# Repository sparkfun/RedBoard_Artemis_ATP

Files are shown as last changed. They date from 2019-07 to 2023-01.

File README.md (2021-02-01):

SparkFun RedBoard Artemis ATP
============================

SparkFun RedBoard Artemis ATP

[*SparkFun RedBoard Artemis ATP (DEV-15442)*](https://www.sparkfun.com/products/15442)

The RedBoard Artemis ATP is affectionately called 'All the Pins!' at SparkFun. The Artemis module has 48 GPIO and this board breaks out absolutely every one of them in a familiar Mega like form factor. What's with the silkscreen labels? They're all over the place. We decided to label the pins as they are assigned on the Apollo3 IC itself. This makes finding the pin with the function you desire a lot easier. Have a look at the [full pin map](https://cdn.sparkfun.com/assets/8/2/3/3/c/Apollo3_Pad_Mapping.pdf) from the Apollo3 datasheet. If you really need to test out the 4-bit SPI functionality of the Artemis you're going to need to access pins 4, 22, 23, and 26. Need to try out the differential ADC port 1? Pins 14 and 15. The RedBoard Artemis ATP will allow you to flex the impressive capabilities of the Artemis module.

The RedBoard Artemis ATP has the improved power conditioning and USB to serial that we've refined over the years on our RedBoard line of products. A modern USB-C connector make programming easy. A Qwiic connector makes I<sup>2</sup>C easy. The ATP is fully compatible with SparkFun's Arduino core and can be programmed easily under the Arduino IDE. We've exposed the JTAG connector for more advanced users who prefer to use the power and speed of professional tools. If you need a *lot* of a GPIO with a simple to program, ready to go to market module, the ATP is the fix you need. We've added a digital MEMS microphone for folks wanting to experiment with always-on voice commands with TensorFlow and machine learning. We've even added a convenient jumper to measure current consumption for low power testing.

With 1M flash and 384k RAM you'll have plenty of room for your sketches. The Artemis module runs at 48MHz with a 96MHz turbo mode available and with Bluetooth to boot!

The SparkFun RedBoard Artemis ATP is a powerful platform if you're interesting in testing out the full capabilities of the SparkFun Artemis module. If you're looking for more compact solution, be sure to checkout our Nano and Uno footprints for more hacker friendly products.

Repository Contents
-------------------
* **/Hardware** - Eagle design files (.brd, .sch)

Documentation
-------------------
* **[Hookup Guide for the RedBoard Artemis ATP](https://learn.sparkfun.com/tutorials/hookup-guide-for-the-sparkfun-redboard-artemis-atp)**
* **[Artemis Development with Arduino](https://learn.sparkfun.com/tutorials/artemis-development-with-arduino)**
* **[Ambiq Apollo3 SDK SetUp](https://learn.sparkfun.com/tutorials/using-sparkfun-edge-board-with-ambiq-apollo3-sdk)**
* **[Designing with the SparkFun Artemis](https://learn.sparkfun.com/tutorials/designing-with-the-sparkfun-artemis)**
* **[CH340E USB to serial IC Drivers](https://www.sparkfun.com/ch340)**

License Information
-------------------

This product is _**open source**_! 

Please review the LICENSE.md file for license information. 

If you have any questions or concerns on licensing, please contact techsupport@sparkfun.com.

Please use, reuse, and modify these files as you see fit. Please maintain attribution to SparkFun Electronics and release any derivative under the same license.

Distributed as-is; no warranty is given.

- Your friends at SparkFun.

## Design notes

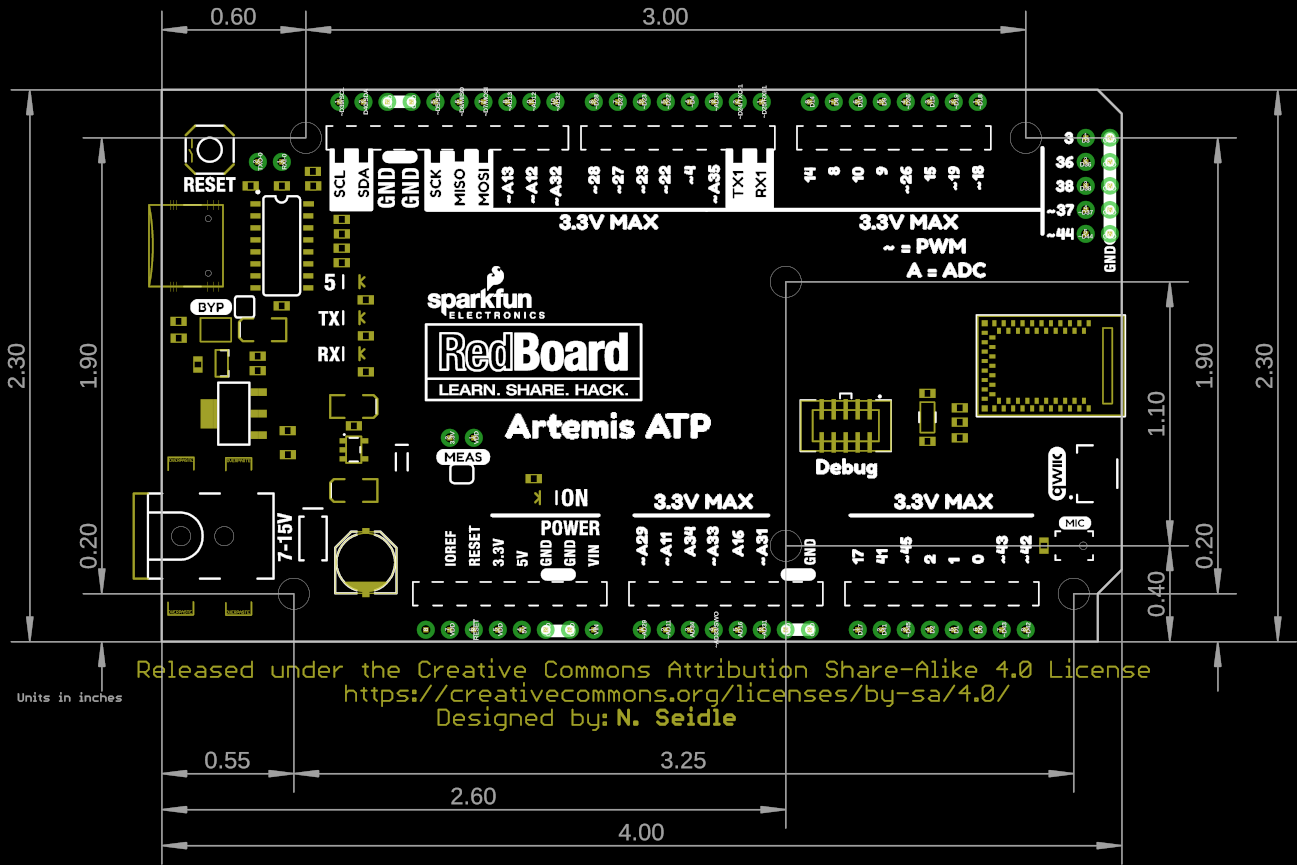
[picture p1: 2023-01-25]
Hardware/Artemis_ATP_Dimensions.png

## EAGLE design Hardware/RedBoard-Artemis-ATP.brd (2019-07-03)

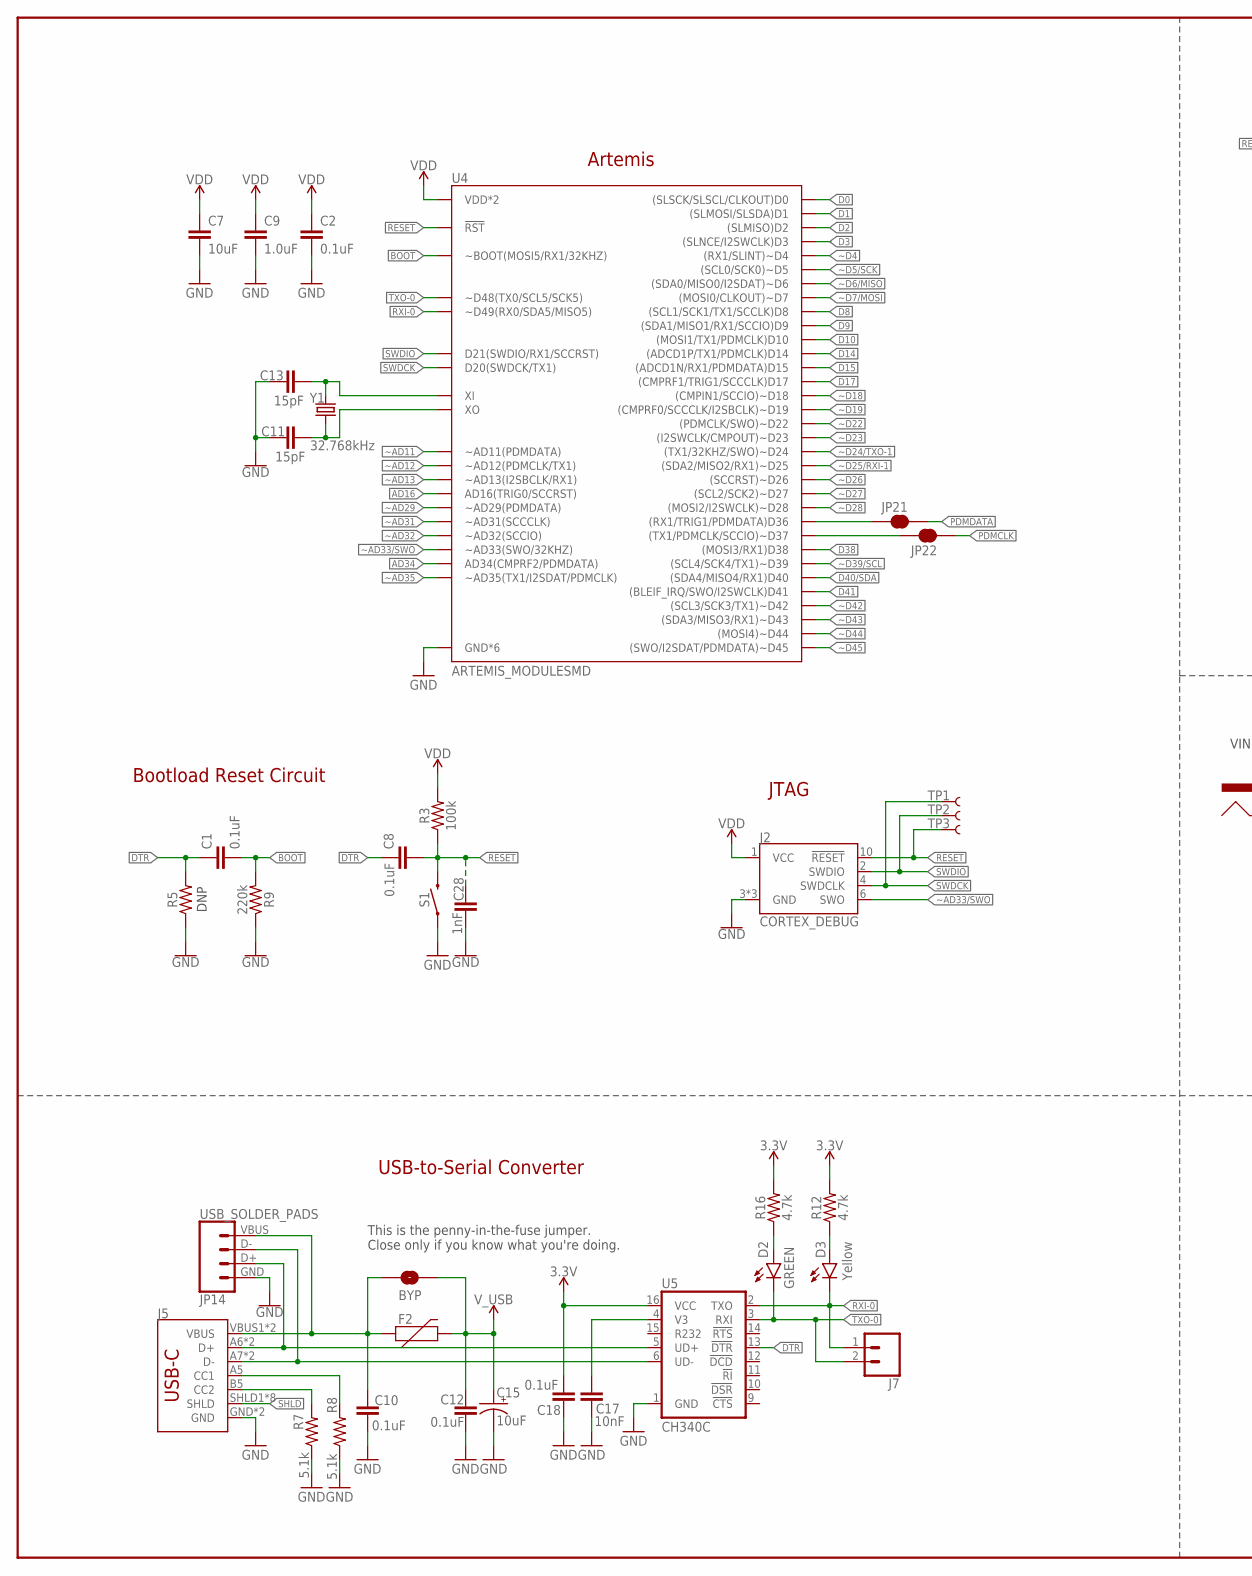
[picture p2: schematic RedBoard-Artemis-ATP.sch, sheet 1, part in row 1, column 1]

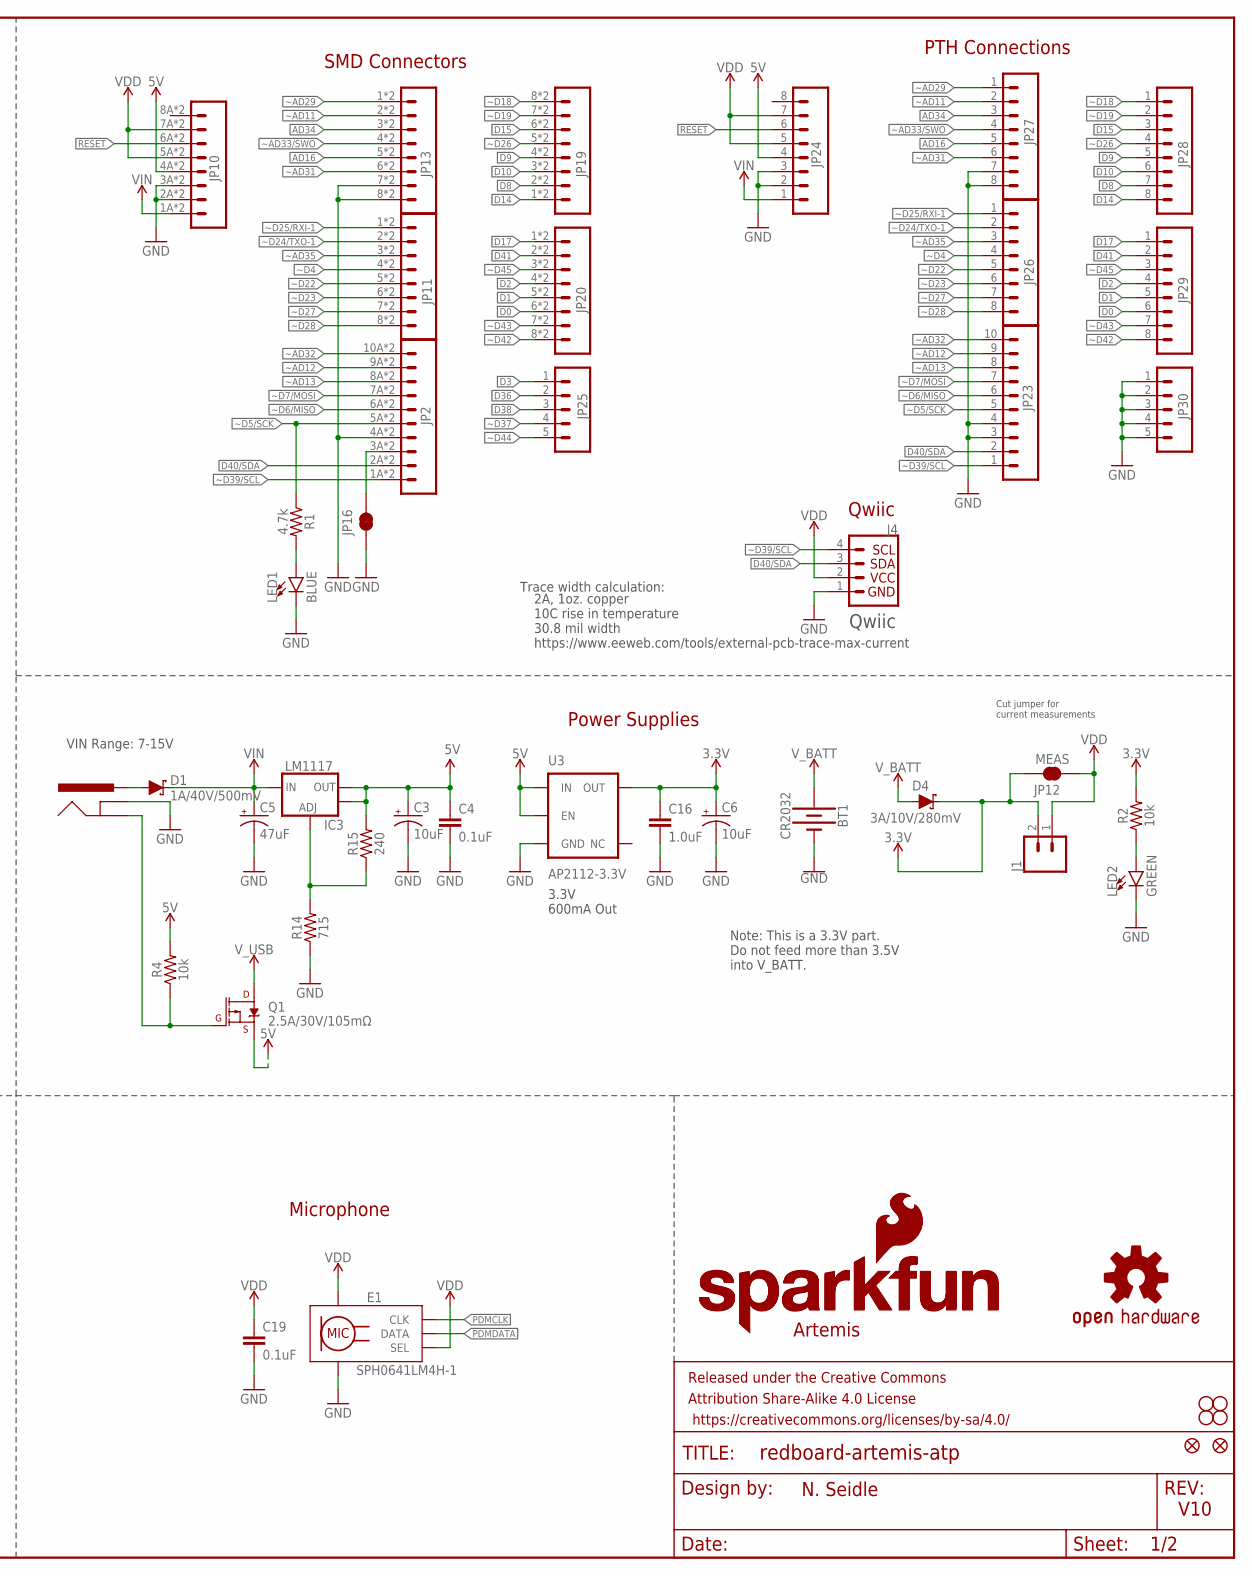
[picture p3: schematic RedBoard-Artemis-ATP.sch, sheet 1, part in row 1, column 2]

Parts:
BT1: CR2032; BATTCON_20MM_4LEGS_OVERPASTE
BYP: BYP; SMT-JUMPER_2_NO_SILK
C1, C2, C4, C8, C10, C12, C18, C19: 0.1uF; 0603
C3, C6, C15: 10uF; EIA3216
C5: 47uF; PANASONIC_D
C7: 10uF; 0603
C9, C16: 1.0uF; 0603
C11, C13: 15pF; 0603
C17: 10nF; 0603
C28: 1nF; 0603
D1: 1A/40V/500mV; SMA-DIODE
D2: GREEN; LED-1206
D3: Yellow; LED-1206
D4: 3A/10V/280mV; SOD-323
E1: SPH0641LM4H-1; SPH0641LM4H-1_MICROPHONE
F2: 6V/2A; 1210
FRAME3: FRAME-LEDGER; CREATIVE_COMMONS
IC3: LM1117; SOT223-ALT1
J1, J7: CONN_021X02_NO_SILK; 1X02_NO_SILK
J2: CORTEX_DEBUG; 2X5-SMD-1.27MM
J3: POWER_JACKTOE; POWER_JACK_SMD_OVERPASTE_TOE
J4: QWIIC_CONNECTORJS-1MM; JST04_1MM_RA
J5: USB-C; USB-C-16P
JP1: SFE_LOGO_NAME.1_INCH; SFE_LOGO_NAME_.1
JP2: CONN_10SMD_COMBO-FEMALE; 1X10_SMD_COMBINED
JP3, JP4, JP5, JP6: STAND-OFF
JP7: SFE_LOGO_FLAME.1_INCH; SFE_LOGO_FLAME_.1
JP8, JP9: FIDUCIAL1X2; FIDUCIAL-1X2
JP10: M08SMD-COMBO; 1X08_SMD_COMBINED@1
JP11, JP13, JP19, JP20: CONN_08SMD-COMBO-FEMALE_NC; 1X08_SMD_COMBINED_NC
JP12: MEAS; SMT-JUMPER_2_NC_TRACE_SILK
JP14: USB_SOLDER_PADS; USB-SOLDER-PADS
JP16, JP21, JP22: JUMPER-SMT_2_NC_TRACE_SILK; SMT-JUMPER_2_NC_TRACE_SILK
JP23: M10NO_SILK; 1X10_NO_SILK@1
JP24: M08NO_SILK; 1X08_NO_SILK@1
JP25, JP30: CONN_05NO_SILK; 1X05_NO_SILK
JP26, JP27, JP28, JP29: CONN_08NO_SILK_FEMALE_PTH; 1X08_NO_SILK
LED1: BLUE; LED-1206
LED2: GREEN; LED-1206
LOGO1: SFE_LOGO_NAME_FLAME.1_INCH; SFE_LOGO_NAME_FLAME_.1
Q1: 2.5A/30V/105mΩ; SOT23-3
R1, R12, R16: 4.7k; 0603
R2, R4: 10k; 0603
R3: 100k; 0603
R5: 0603
R7, R8: 5.1k; 0603
R9: 220k; 0603
R14: 715; 0603
R15: 240; 0603
S1: MOMENTARY-SWITCH-SPST-SMD-5.2-TALL-REDUNDANT; TACTILE_SWITCH_SMD_5.2MM
TP1, TP2, TP3: TEST-POINT3X5; PAD.03X.05
U3: AP2112-3.3V; SOT23-5
U4: ARTEMIS_MODULESMD; ARTEMIS_FP
U5: CH340C; SO016
U$16: OSHW-LOGOS; OSHW-LOGO-S
Y1: 32.768kHz; CRYSTAL-SMD-3.2X1.5MM

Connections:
3.3V: C6.+, C16.1, C18.1, D4.C, J1.2, JP12.1, R2.2, R12.2, R16.2, U3.5 (OUT), U5.16 (VCC)
5V: C3.+, C4.1, IC3.2 (OUT), IC3.4 (OUT), JP10.4A (4), JP10.4B (4), JP24.4, Q1.2 (S), R4.2, R15.2, U3.1 (IN), U3.3 (EN)
!DTR: C1.1, C8.1, R5.2, U5.13 (!DTR)
!RESET: C8.2, C28.1, J2.10 (!RESET), JP10.6A (6), JP10.6B (6), JP24.6, R3.1, S1.3 (2), S1.4 (2), TP3.P$1, U4.~RST (!RST)
AD16: JP13.5, JP13.5@2 (5), JP27.5, U4.AD16 (AD16(TRIG0/SCCRST))
AD34: JP13.3, JP13.3@2 (3), JP27.3, U4.AD34 (AD34(CMPRF2/PDMDATA))
BOOT: C1.2, R9.2, U4.BOOT (~BOOT(MOSI5/RX1/32KHZ))
CC1: J5.A5 (CC1), R8.2
CC2: J5.B5 (CC2), R7.2
D0: JP20.6, JP20.6@2 (6), JP29.6, U4.D0 ((SLSCK/SLSCL/CLKOUT)D0)
D1: JP20.5, JP20.5@2 (5), JP29.5, U4.D1 ((SLMOSI/SLSDA)D1)
D2: JP20.4, JP20.4@2 (4), JP29.4, U4.D2 ((SLMISO)D2)
D3: JP25.1, U4.D3 ((SLNCE/I2SWCLK)D3)
D8: JP19.2, JP19.2@2 (2), JP28.7, U4.D8 ((SCL1/SCK1/TX1/SCCLK)D8)
D9: JP19.4, JP19.4@2 (4), JP28.5, U4.D9 ((SDA1/MISO1/RX1/SCCIO)D9)
D10: JP19.3, JP19.3@2 (3), JP28.6, U4.D10 ((MOSI1/TX1/PDMCLK)D10)
D14: JP19.1, JP19.1@2 (1), JP28.8, U4.D14 ((ADCD1P/TX1/PDMCLK)D14)
D15: JP19.6, JP19.6@2 (6), JP28.3, U4.D15 ((ADCD1N/RX1/PDMDATA)D15)
D17: JP20.1, JP20.1@2 (1), JP29.1, U4.D17 ((CMPRF1/TRIG1/SCCCLK)D17)
D36: JP21.1, JP25.2, U4.D36 ((RX1/TRIG1/PDMDATA)D36)
D38: JP25.3, U4.D38 ((MOSI3/RX1)D38)
D40/SDA: J4.3, JP2.2A (2), JP2.2B (2), JP23.2, U4.D40 ((SDA4/MISO4/RX1)D40)
D41: JP20.2, JP20.2@2 (2), JP29.2, U4.D41 ((BLEIF_IRQ/SWO/I2SWCLK)D41)
D+: J5.A6 (D+), J5.B6 (D+), JP14.D+ (3), U5.5 (UD+)
D-: J5.A7 (D-), J5.B7 (D-), JP14.D- (2), U5.6 (UD-)
GND: BT1.2 (-), C2.1, C3.-, C4.2, C5.-, C6.-, C7.2, C9.2, C10.2, C11.1, C12.2, C13.1, C15.-, C16.2, C17.2, C18.2, C19.2, C28.2, E1.3 (GND), E1.6 (GND), E1.7 (GND), E1.8 (GND), J2.3 (GND), J2.5 (GND), J2.9 (GND), J3.GND (GNDBREAK), J4.1, J5.GND, J5.GND2 (GND), JP2.4A (4), JP2.4B (4), JP10.2A (2), JP10.2B (2), JP10.3A (3), JP10.3B (3), JP13.7, JP13.7@2 (7), JP13.8, JP13.8@2 (8), JP14.GND (4), JP16.1, JP23.3, JP23.4, JP24.2, JP24.3, JP27.7, JP27.8, JP30.1, JP30.2, JP30.3, JP30.4, JP30.5, LED1.C, LED2.C, R5.1, R7.1, R8.1, R9.1, R14.1, S1.1, S1.2 (1), U3.2 (GND), U4.GND@1 (GND*6), U4.GND@22 (GND*6), U4.GND@38 (GND*6), U4.GND@39 (GND*6), U4.GND@47 (GND*6), U4.GND@59 (GND*6), U5.1 (GND)
INSERT: J3.P$4 (GND), Q1.1 (G), R4.1
unnamed: LED1.A, R1.2
unnamed: LED2.A, R2.1
unnamed: D2.A, R16.1
unnamed: C17.1, U5.4 (V3)
unnamed: C11.2, U4.XO, Y1.P$2 (2)
unnamed: C13.2, U4.XI, Y1.P$1 (1)
unnamed: D3.A, R12.1
unnamed: JP2.3A (3), JP2.3B (3), JP16.2
unnamed: IC3.1 (ADJ), R14.2, R15.1
PDMCLK: E1.4 (CLK), JP22.2
PDMDATA: E1.1 (DATA), JP21.2
PWRIN: D1.A, J3.VIN0 (PWR)
RXI-0: D3.C, J7.1, U4.RXI-0 (~D49(RX0/SDA5/MISO5)), U5.2 (TXO)
SHLD: J5.SHLD1 (SHLD), J5.SHLD2 (SHLD), J5.SHLD3 (SHLD), J5.SHLD4 (SHLD), J5.SHLD5 (SHLD), J5.SHLD6 (SHLD), J5.SHLD7 (SHLD), J5.SHLD8 (SHLD)
SWDCK: J2.4 (SWDCLK), TP1.P$1, U4.SWDCK (D20(SWDCK/TX1))
SWDIO: J2.2 (SWDIO), TP2.P$1, U4.SWDIO (D21(SWDIO/RX1/SCCRST))
TXO-0: D2.C, J7.2, U4.TXO-0 (~D48(TX0/SCL5/SCK5)), U5.3 (RXI)
VDD: C2.2, C7.1, C9.1, C19.1, E1.2 (SEL), E1.5 (VDD), J1.1, J2.1 (VCC), J4.2, JP10.5A (5), JP10.5B (5), JP10.7A (7), JP10.7B (7), JP12.2, JP24.5, JP24.7, R3.2, U4.VDD@36 (VDD*2), U4.VDD@37 (VDD*2)
VIN: C5.+, D1.C, IC3.3 (IN), JP10.1A (1), JP10.1B (1), JP24.1
VUSB: BYP.1, C10.1, F2.1, J5.VBUS1 (VBUS), J5.VBUS2 (VBUS), JP14.VBUS (1)
V_BATT: BT1.1 (+), D4.A
V_USB: BYP.2, C12.1, C15.+, F2.2, Q1.3 (D)
~AD11: JP13.2, JP13.2@2 (2), JP27.2, U4.~AD11 (~AD11(PDMDATA))
~AD12: JP2.9A (9), JP2.9B (9), JP23.9, U4.~AD12 (~AD12(PDMCLK/TX1))
~AD13: JP2.8A (8), JP2.8B (8), JP23.8, U4.~AD13 (~AD13(I2SBCLK/RX1))
~AD29: JP13.1, JP13.1@2 (1), JP27.1, U4.~AD29 (~AD29(PDMDATA))
~AD31: JP13.6, JP13.6@2 (6), JP27.6, U4.~AD31 (~AD31(SCCCLK))
~AD32: JP2.10A (10), JP2.10B (10), JP23.10, U4.~AD32 (~AD32(SCCIO))
~AD33/SWO: J2.6 (SWO), JP13.4, JP13.4@2 (4), JP27.4, U4.~AD33/SWO (~AD33(SWO/32KHZ))
~AD35: JP11.3, JP11.3@2 (3), JP26.3, U4.~AD35 (~AD35(TX1/I2SDAT/PDMCLK))
~D4: JP11.4, JP11.4@2 (4), JP26.4, U4.~D4 ((RX1/SLINT)~D4)
~D5/SCK: JP2.5A (5), JP2.5B (5), JP23.5, R1.1, U4.~D5 ((SCL0/SCK0)~D5)
~D6/MISO: JP2.6A (6), JP2.6B (6), JP23.6, U4.~D6 ((SDA0/MISO0/I2SDAT)~D6)
~D7/MOSI: JP2.7A (7), JP2.7B (7), JP23.7, U4.D7 ((MOSI0/CLKOUT)~D7)
~D18: JP19.8, JP19.8@2 (8), JP28.1, U4.~D18 ((CMPIN1/SCCIO)~D18)
~D19: JP19.7, JP19.7@2 (7), JP28.2, U4.~D19 ((CMPRF0/SCCCLK/I2SBCLK)~D19)
~D22: JP11.5, JP11.5@2 (5), JP26.5, U4.~D22 ((PDMCLK/SWO)~D22)
~D23: JP11.6, JP11.6@2 (6), JP26.6, U4.~D23 ((I2SWCLK/CMPOUT)~D23)
~D24/TXO-1: JP11.2, JP11.2@2 (2), JP26.2, U4.~D24 ((TX1/32KHZ/SWO)~D24)
~D25/RXI-1: JP11.1, JP11.1@2 (1), JP26.1, U4.~D25 ((SDA2/MISO2/RX1)~D25)
~D26: JP19.5, JP19.5@2 (5), JP28.4, U4.~D26 ((SCCRST)~D26)
~D27: JP11.7, JP11.7@2 (7), JP26.7, U4.~D27 ((SCL2/SCK2)~D27)
~D28: JP11.8, JP11.8@2 (8), JP26.8, U4.~D28 ((MOSI2/I2SWCLK)~D28)
~D37: JP22.1, JP25.4, U4.~D37 ((TX1/PDMCLK/SCCIO)~D37)
~D39/SCL: J4.4, JP2.1A (1), JP2.1B (1), JP23.1, U4.~D39 ((SCL4/SCK4/TX1)~D39)
~D42: JP20.8, JP20.8@2 (8), JP29.8, U4.~D42 ((SCL3/SCK3/TX1)~D42)
~D43: JP20.7, JP20.7@2 (7), JP29.7, U4.~D43 ((SDA3/MISO3/RX1)~D43)
~D44: JP25.5, U4.~D44 ((MOSI4)~D44)
~D45: JP20.3, JP20.3@2 (3), JP29.3, U4.~D45 ((SWO/I2SDAT/PDMDATA)~D45)

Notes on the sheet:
Artemis
USB-to-Serial Converter
N. Seidle
V10
This is the penny-in-the-fuse jumper. Close only if you know what you're doing.
VIN Range: 7-15V
3.3V 600mA Out
Cut jumper for current measurements
Power Supplies
Microphone
Note: This is a 3.3V part. Do not feed more than 3.5V into V_BATT.
Qwiic
Trace width calculation:
2A, 1oz. copper 10C rise in temperature 30.8 mil width https://www.eeweb.com/tools/external-pcb-trace-max-current
Bootload Reset Circuit
JTAG
DNP
PTH Connections
SMD Connectors

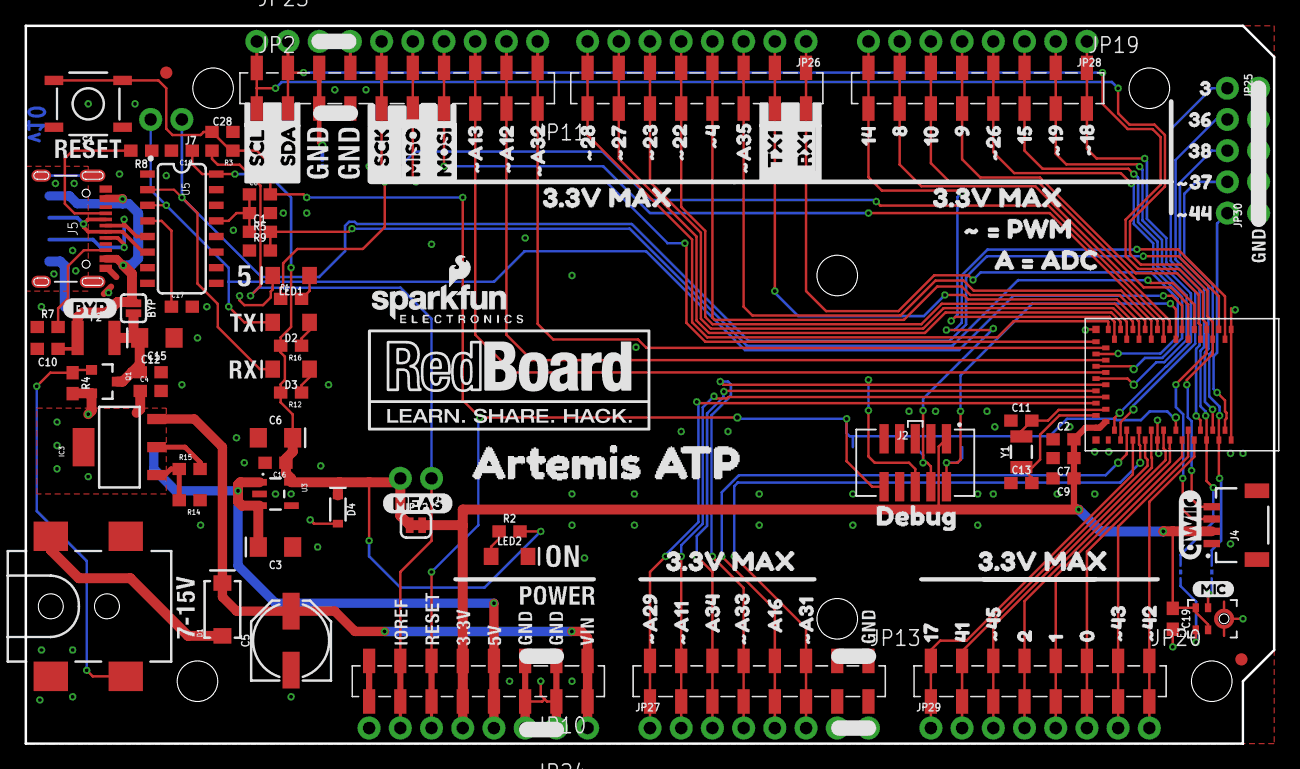
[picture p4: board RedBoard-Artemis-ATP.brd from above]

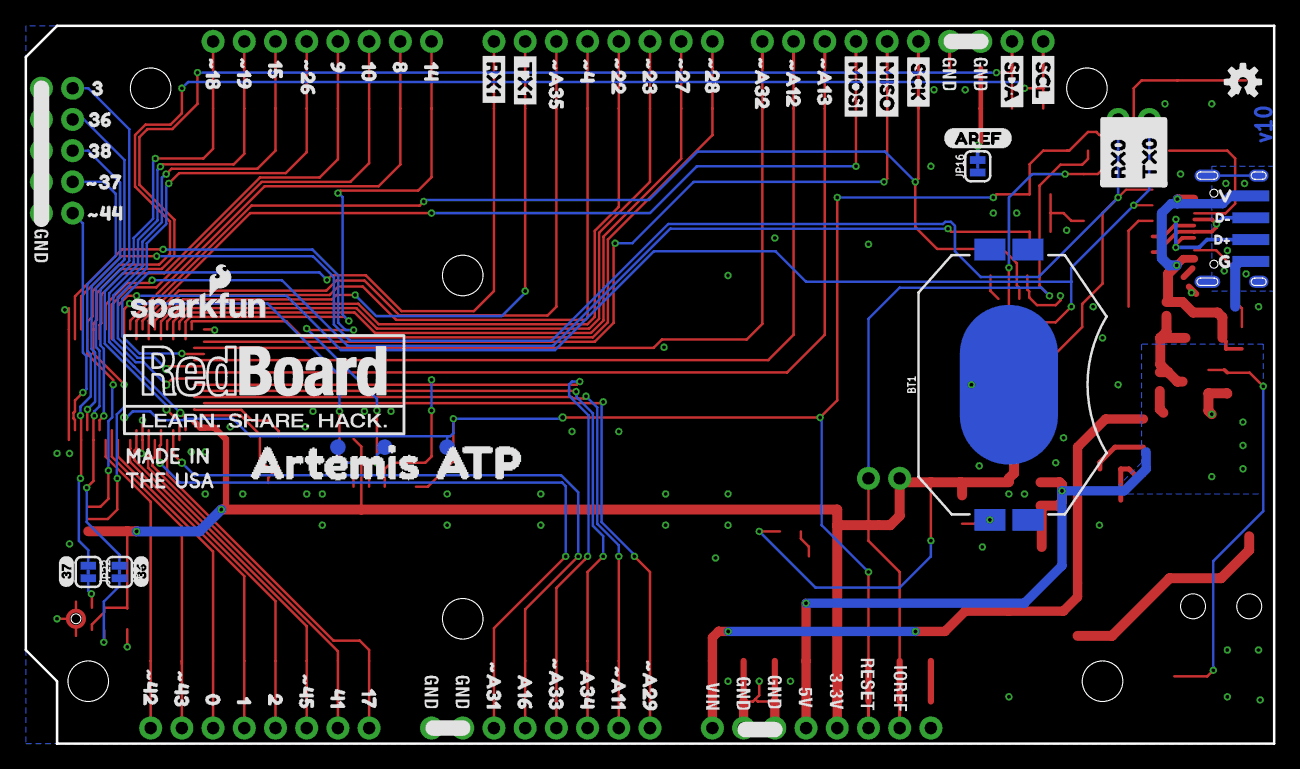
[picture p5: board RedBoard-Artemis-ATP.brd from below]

Board: 2 copper layers, 101.6 x 58.4 mm, 201 parts (66 on the bottom side), 76 nets.

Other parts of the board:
FRAME2: FRAME-LETTERNO_PACKAGE; DUMMY
JP17, JP18: STAND-OFF
U$1, U$65, U$67, U$73: 3#3V_MAX2
U$2: D#3
U$3, U$58: 1720
U$4: MADEINUSA#PNG
U$9: QWIIC_COPYRIGHT_SMALL
U$10: D#4
U$11: G1
U$12: V0
U$13, U$112: #A332
U$14, U$15: ARTEMIS0
U$17, U$113: A160
U$18, U$108: SCL1
U$19, U$96: #48
U$20: AREF2
U$21, U$97: #229
U$22, U$107: SDA0
U$23, U$93: #3711
U$24, U$89: #187
U$25, U$98: #2310
U$26, U$100: #2711
U$27, U$99: #2812
U$28, U$61: ATP1
U$29, U$110: #A113
U$30, U$109: #A294
U$31, U$114: #A310
U$32, U$88: #196
U$33, U$95: #A357
U$34, U$102: #A1214
U$35, U$103: #A1315
U$36, U$101: #A3213
U$37, U$86: #264
U$38, U$111: A342
U$39, U$81: #4213
U$40, U$80: #4314
U$41, U$94: #4412
U$42, U$75: #4518
U$43, U$79: 015
U$44, U$90: 38
U$45, U$83: 81
U$46, U$85: 93
U$47, U$105: MISO8
U$48, U$104: MOSI7
U$49: RX01
U$50, U$106: SCK9
U$51, U$84: 102
U$52, U$78: 116
U$53: TX00
U$54, U$82: 140
U$55, U$87: 155
U$56, U$77: 217
U$57, U$91: 369
U$59, U$92: 3810
U$60, U$74: 4119
U$62: MIC0
U$63: 364
U$64: 373
U$66: #_#_PWM7
U$68: BYP0
U$69: A_#_ADC6
U$70: MEAS3
U$71, U$115: RX11
U$72, U$116: TX10
U$76: DEBUG2

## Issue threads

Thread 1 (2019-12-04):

Expose ITM/SWO pin on SWD/JTAG Connector

oclyke, 2019-12-04:
Will you consider adding a free ITM/SWO pin to the SWD/JTAG connector as is demonstrated on the [Edge](https://cdn.sparkfun.com/assets/2/b/7/4/d/SparkFun_Edge_Schematic.pdf) board? This affords users a different ('pro') way to do debug printing and possibly frees up a UART for another purpose. Inspired by https://github.com/sparkfun/SparkFun_Apollo3_AmbiqSuite_BSPs/issues/19

oclyke, 2019-12-13:
OOPS. I totally overlooked the SWO pin here and made all this fuss over nothing. Sorry!

Closed 2019-12-13.

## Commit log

2019-07-01 Remove old files. Rename to RedBoard.
    [BlackBoard-Artemis-ATP-Panel.GBL, BlackBoard-Artemis-ATP-Panel.GBO, BlackBoard-Artemis-ATP-Panel.GBS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]
2019-07-02 Add SMD Debug. Add PTH holes to each connector.
    [RedBoard-Artemis-ATP.brd, RedBoard-Artemis-ATP.sch]
2019-07-02 Add silk indicators to PTH pins
    [RedBoard-Artemis-ATP.brd, RedBoard-Artemis-ATP.sch]
2019-07-03 Consolidated to one sch sheet.
    [RedBoard-Artemis-ATP.brd, RedBoard-Artemis-ATP.sch]
2019-07-03 Approved DRC errors
    [RedBoard-Artemis-ATP.brd]
2019-07-03 Adding production panels
    [RedBoard-Artemis-ATP-Panel.GBL, RedBoard-Artemis-ATP-Panel.GBO, RedBoard-Artemis-ATP-Panel.GBP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]
2019-07-03 Adding designed by text
    [RedBoard-Artemis-ATP.brd]

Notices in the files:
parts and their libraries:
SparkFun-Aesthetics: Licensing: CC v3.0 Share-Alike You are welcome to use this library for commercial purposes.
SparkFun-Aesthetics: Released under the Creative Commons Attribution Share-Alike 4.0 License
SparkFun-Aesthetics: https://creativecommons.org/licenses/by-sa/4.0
